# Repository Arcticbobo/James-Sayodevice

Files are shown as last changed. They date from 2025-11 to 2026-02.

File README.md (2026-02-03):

# James-Sayodevice
Repository containing files for a custom sayodevice
I created this macropad to allow me to play osu! on the go, and become more efficient when Designing mechanisms for my vex V5 team.

Overall design:


Schematic for circuit:


PCB:


Case Design:


BOM:
 - 4x Cherry MX keyboard switch
 - 1x XIAO RP2040 
 - 2x SK6812MINI-E LED
 - 4x Blank DSA keycaps
 - 4x M3x16mm screws
 - 4x M3x5mx4mm heatset inserts
 - 1x 0.91 inch OLED display

Custom:
 - case lid.stl
 - case base.stl
 - KMK Firmware (I will finish adding code for display once I have hardware for troubleshooting purposes)

Final Product
IMG_1826 (1)
After some struggles, tweaking, tinkering, and testing, here is the final product!

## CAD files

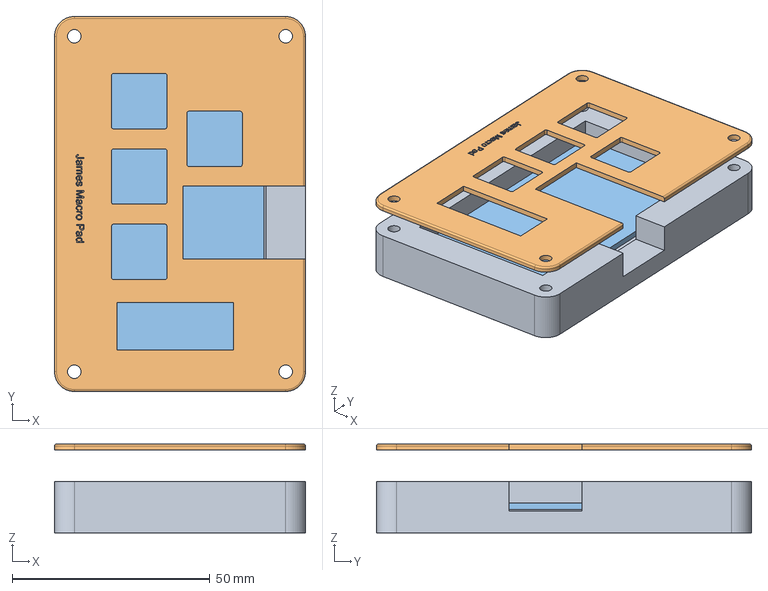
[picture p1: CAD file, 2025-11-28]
CAD/Fully assembled macro pad v2.step
63.5 x 94.8 x 22.5 mm
Case base v2
Case Lid v2

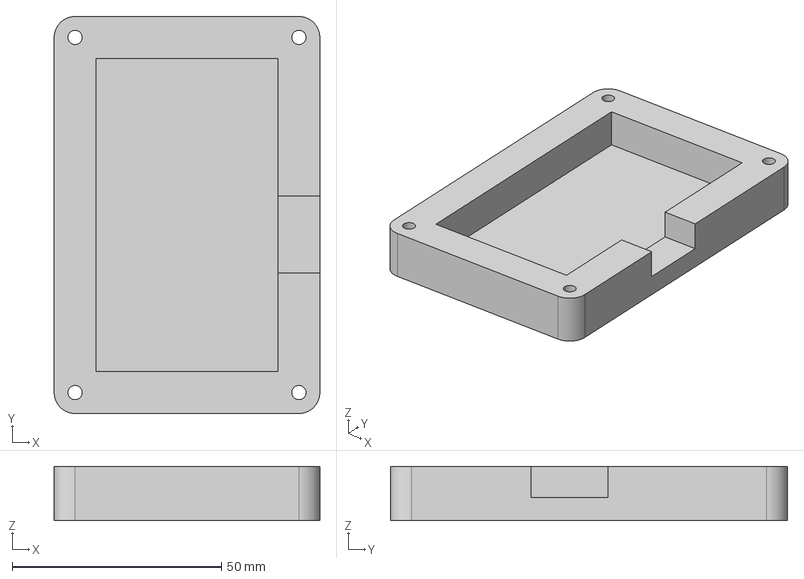
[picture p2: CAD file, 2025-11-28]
CAD/Case Base v2.step
63.5 x 94.8 x 13.0 mm

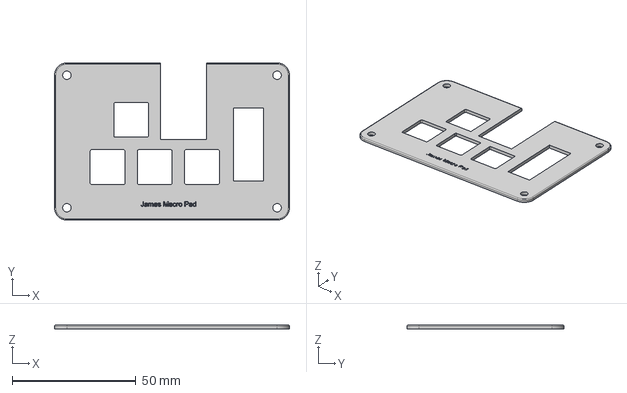
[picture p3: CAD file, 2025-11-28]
CAD/Case Lid v2.step
94.8 x 63.5 x 1.50 mm

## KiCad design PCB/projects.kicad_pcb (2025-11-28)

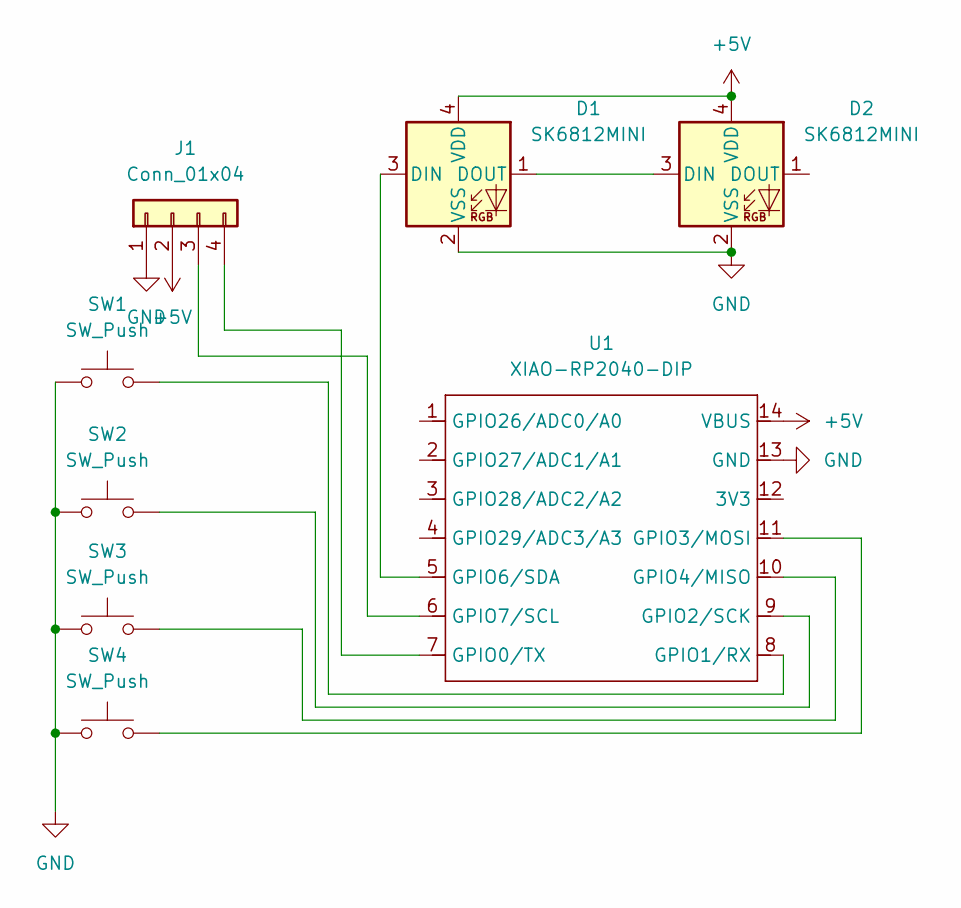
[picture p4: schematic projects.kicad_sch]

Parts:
D1, D2: SK6812MINI; LED_SK6812MINI_PLCC4_3.5x3.5mm_P1.75mm
J1: Conn_01x04; SSD1306-0.91-OLED-4pin-128x32
SW1, SW2, SW3, SW4: SW_Push; SW_Cherry_MX_1.00u_PCB
U1: XIAO-RP2040-DIP

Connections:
+5V: D1.4 (VDD), D2.4 (VDD), J1.2, U1.14 (VBUS)
GND: D1.2 (VSS), D2.2 (VSS), J1.1, SW1.1, SW2.1, SW3.1, SW4.1, U1.13 (GND)
unnamed: D1.3 (DIN), U1.5 (GPIO6/SDA)
unnamed: D1.1 (DOUT), D2.3 (DIN)
unnamed: J1.3, U1.6 (GPIO7/SCL)
unnamed: J1.4, U1.7 (GPIO0/TX)
unnamed: SW1.2, U1.8 (GPIO1/RX)
unnamed: SW2.2, U1.9 (GPIO2/SCK)
unnamed: SW4.2, U1.11 (GPIO3/MOSI)
unnamed: SW3.2, U1.10 (GPIO4/MISO)

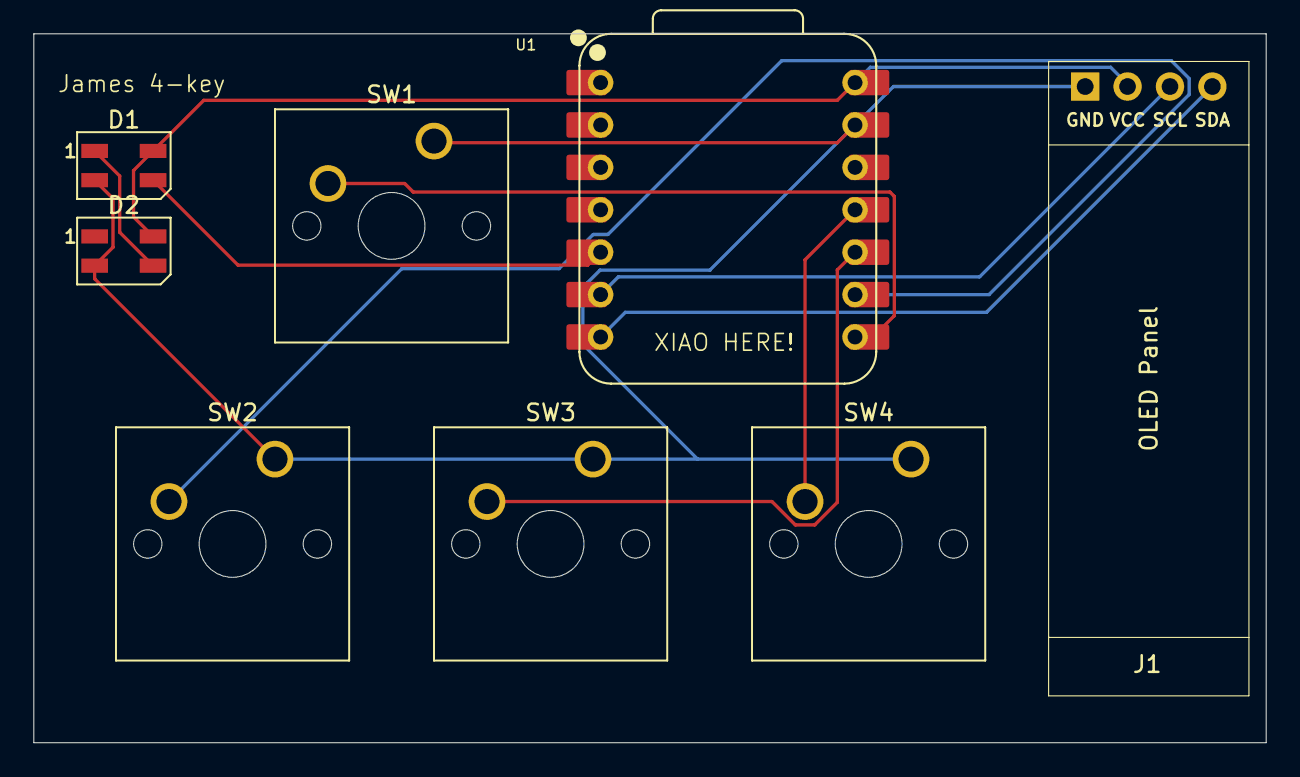
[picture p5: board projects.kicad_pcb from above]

Board: 2 copper layers, 73.8 x 42.5 mm, 8 parts (0 on the bottom side), 10 nets.

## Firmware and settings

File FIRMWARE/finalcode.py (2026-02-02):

import board
import adafruit_bitbangio
import time
import gc
from kmk.kmk_keyboard import KMKKeyboard
from kmk.scanners.keypad import KeysScanner
from kmk.keys import KC

# 1. THE STABLE DRIVER
class SSD1306_Miku:
    def __init__(self, i2c):
        self.i2c = i2c
        self.addr = 0x3C

        # Initialization Sequence
        init_cmds = [
            0xAE, 0x20, 0x00, 0xD5, 0x80, 0xA8, 0x1F, 0xD3, 0x00,
            0x40, 0x8D, 0x14, 0xA1, 0xC8, 0xDA, 0x02, 0x81, 0x7F,
            0xD9, 0xF1, 0xDB, 0x40, 0xA4, 0xA6, 0xAF
        ]
        self._send_cmds(init_cmds)

    def _send_cmds(self, cmds):
        while not self.i2c.try_lock(): pass
        try:
            for cmd in cmds:
                self.i2c.writeto(self.addr, bytes([0x00, cmd]))
        finally:
            self.i2c.unlock()

    def update(self, buf):
        while not self.i2c.try_lock(): pass
        try:
            # Tell OLED to reset cursor to top-left (0,0)
            # This prevents the "Shift/Wrap" bug
            self.i2c.writeto(self.addr, b'\x00\x21\x00\x7f\x22\x00\x03')
            # Send the pixels
            self.i2c.writeto(self.addr, b'\x40' + buf)
        finally:
            self.i2c.unlock()

# 2. HARDWARE SETUP
# Frequency lowered to 400000 for Bitbang stability
i2c_bus = adafruit_bitbangio.I2C(board.D5, board.D6, frequency=400000)
oled = SSD1306_Miku(i2c_bus)

# 3. BITMAPS (Condensed)
MIKU_OPEN = bytearray([


0xff, 0xff, 0xff, 0xff, 0xff, 0xff, 0xff, 0xff, 0x1f, 0x8f, 0xc7, 0xe1, 0xf8, 0xfc, 0xff, 0xff,
    0xff, 0xff, 0x7f, 0x0f, 0xc3, 0x01, 0x00, 0x00, 0x70, 0x0e, 0x03, 0x40, 0x30, 0xce, 0xfb, 0xff,
    0xff, 0xff, 0x7f, 0x3f, 0x07, 0x21, 0xc0, 0xf9, 0xfd, 0x7f, 0x7d, 0x7d, 0x7d, 0x7f, 0x7f, 0xff,
    0xbf, 0xff, 0xff, 0xff, 0xff, 0xff, 0x00, 0x0f, 0x3f, 0xff, 0xff, 0xff, 0xff, 0xff, 0xff, 0xff,
    0x0f, 0xff, 0x00, 0x00, 0xfe, 0xfd, 0xfd, 0xf5, 0x75, 0x6d, 0x5d, 0x3f, 0x7d, 0x7f, 0xff, 0xff,
    0x7f, 0xff, 0xff, 0xff, 0xfc, 0xef, 0x1f, 0x3f, 0xf0, 0x00, 0x00, 0x07, 0xf8, 0x40, 0x00, 0x02,
    0x08, 0x00, 0x00, 0xe7, 0xff, 0xff, 0xff, 0xff, 0xff, 0xff, 0xff, 0xfe, 0xf0, 0x81, 0x07, 0x1f,
    0x7f, 0xff, 0xff, 0xff, 0xff, 0xff, 0xff, 0xff, 0xff, 0xff, 0xff, 0xff, 0xff, 0xff, 0xff, 0xff,
    0xff, 0xff, 0xff, 0x7f, 0x0f, 0x83, 0xe1, 0x38, 0x1e, 0xe7, 0xf3, 0xff, 0xff, 0xff, 0x7f, 0x3f,
    0xff, 0xc1, 0x78, 0x0f, 0x03, 0x00, 0xe0, 0x18, 0x00, 0x00, 0x00, 0x80, 0xf8, 0xff, 0xff, 0x01,
    0xff, 0x7f, 0x00, 0x00, 0x00, 0x01, 0xe1, 0xf0, 0x38, 0x08, 0x00, 0x00, 0x10, 0x38, 0x38, 0x10,
    0x01, 0x03, 0x1f, 0xff, 0xff, 0xff, 0xff, 0xfe, 0xf8, 0xe1, 0xe3, 0xcc, 0x81, 0x87, 0x8f, 0x1c,
    0x00, 0xf3, 0xfc, 0xf7, 0x0b, 0x01, 0x00, 0x38, 0x38, 0x18, 0x00, 0x00, 0x00, 0x0c, 0x38, 0xf0,
    0xe1, 0x01, 0x07, 0x0f, 0xff, 0xff, 0xff, 0xf8, 0x00, 0x00, 0x00, 0x00, 0x00, 0x00, 0x00, 0x1e,
    0xe0, 0x00, 0x00, 0x01, 0x3f, 0xff, 0xe3, 0x1f, 0xff, 0xff, 0xff, 0xff, 0xff, 0xfb, 0xe7, 0x18,
    0x30, 0xc1, 0x07, 0x0f, 0x7f, 0xff, 0xff, 0xff, 0xff, 0xff, 0xff, 0xff, 0xff, 0xff, 0xff, 0xff,
    0xff, 0x07, 0x81, 0xf0, 0x0e, 0x03, 0xc0, 0xf8, 0xff, 0xff, 0xff, 0xff, 0x1f, 0x03, 0x00, 0x00,
    0xff, 0x07, 0x00, 0x00, 0x00, 0x00, 0x00, 0x00, 0xf8, 0xf8, 0x80, 0x3f, 0xff, 0xff, 0xff, 0x00,
    0x01, 0x80, 0x00, 0x1c, 0xf8, 0xd0, 0xbf, 0xff, 0xfc, 0xf0, 0xec, 0xd0, 0x98, 0xb0, 0xb0, 0xd8,
    0xd4, 0xe0, 0xf8, 0xff, 0xff, 0xff, 0xff, 0xff, 0xff, 0xff, 0xff, 0xff, 0xff, 0xff, 0xff, 0xff,
    0xff, 0xff, 0xff, 0xff, 0xf0, 0xe8, 0xd0, 0x98, 0xb0, 0xb0, 0x98, 0xd8, 0xe0, 0xf0, 0xfc, 0xff,
    0xff, 0xf0, 0x38, 0x00, 0x07, 0xff, 0x03, 0x07, 0x1f, 0x00, 0x80, 0xf8, 0xff, 0xff, 0xfc, 0xf0,
    0x80, 0x06, 0x00, 0x00, 0x00, 0x0f, 0xff, 0xf8, 0x00, 0x03, 0x1f, 0x7f, 0xff, 0xff, 0xff, 0xff,
    0xfc, 0xc1, 0x03, 0x0e, 0x38, 0x70, 0xc3, 0x0f, 0x1f, 0x7f, 0xff, 0xff, 0xff, 0xff, 0xff, 0xff,
    0x01, 0x78, 0x0f, 0x01, 0x00, 0xfc, 0xff, 0xff, 0xff, 0xff, 0x0f, 0x01, 0x00, 0x00, 0x00, 0x00,
    0x0f, 0x80, 0x00, 0x00, 0x00, 0x00, 0x00, 0x00, 0xff, 0xff, 0xff, 0xfc, 0xf9, 0xef, 0xdf, 0x3e,
    0x60, 0xc0, 0x00, 0x00, 0x00, 0x83, 0x0f, 0x1f, 0x3f, 0x3f, 0x3c, 0x7f, 0x7f, 0x7f, 0xff, 0xff,
    0xff, 0xff, 0xff, 0xff, 0xff, 0xff, 0xff, 0xdf, 0xdf, 0xbf, 0xff, 0xff, 0xff, 0xbf, 0xff, 0xdf,
    0xff, 0xff, 0xff, 0xff, 0xff, 0xff, 0xff, 0xff, 0xff, 0xff, 0x7f, 0x7f, 0x3f, 0x3f, 0x1f, 0x0f,
    0x07, 0x83, 0x40, 0x00, 0x1c, 0x83, 0xe0, 0xf0, 0x80, 0xf8, 0xff, 0xff, 0xff, 0xff, 0xff, 0xff,
    0xff, 0x00, 0x00, 0x00, 0x00, 0x00, 0xc0, 0x0f, 0x00, 0x00, 0x00, 0x00, 0x03, 0x3f, 0xff, 0xff,
    0xff, 0xff, 0xfe, 0x00, 0x00, 0x00, 0x01, 0x03, 0x1c, 0x78, 0xe0, 0x03, 0x07, 0xff, 0xff, 0xff

])
# 4. KMK CORE
keyboard = KMKKeyboard()
keyboard.matrix = KeysScanner(pins=[board.D7, board.D8, board.D9, board.D10], value_when_pressed=False)
keyboard.keymap = [[KC.S, KC.ESC, KC.SPC, KC.C]]

if __name__ == '__main__':
    # Initial draw
    oled.update(MIKU_OPEN)
    gc.collect()
    keyboard.go()
